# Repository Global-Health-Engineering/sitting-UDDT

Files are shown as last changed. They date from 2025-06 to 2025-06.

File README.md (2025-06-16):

<!-- badges: start -->


<!-- badges: end -->

<h1> Sitting Interface for Urine Diverting Dry Toilet </h1>

<b>Contributors</b>  
- Teymour D'Andrea <a href="https://orcid.org/0009-0000-6745-8110">
ORCID logo 0009-0000-6745-8110
</a> *author*  
- Jakub Tkaczuk <a href="https://orcid.org/0000-0001-7997-9423">
ORCID logo 0000-0001-7997-9423
</a> *supervisor, developer, maintainer*  
- Antoinette van der Merwe <a href="https://orcid.org/0000-0003-2489-8479">
ORCID logo 0000-0003-2489-8479
</a> *supervisor*  
- Elizabeth Tilley <a href="https://orcid.org/0000-0002-2095-9724">
ORCID logo 0000-0002-2095-9724
</a> *supervisor*  

<br>
<p align="middle"> 

<br><br>
This repository compliments the openly-accessible master’s thesis, available on the<br \>  
<a href="">ETH Research Collection</a>.
</p>

# Background

This repository compliments the Master's thesis of Teymour D'Andrea's, who adapted an existing open-source user interface of a Urine Diverting Dry Toilet (UDDT), designed by [EOOS](https://urinetrap.com/). The thesis proposes modifications to the design with an aim of making it more suitable for the South Africa’s context (i.e., sitting instead of squatting) and accessible to users of all age.

This repository contains mechanical drawings (both 3D and 2D) of modified steel molds, based on the original open-source concept to cast concrete user interfaces. These interfaces were tested for urine collection efficiency, yielding satisfactory results. Further optimization of the steel mold design is suggested to facilitate easier extraction.

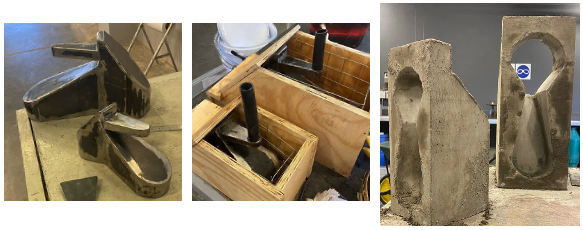
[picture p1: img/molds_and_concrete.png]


# Repository Structure

`cad` directory contains the CAD assemblies for the steel molds of the user interfaces (for adults and children) and the designs for the concrete seats. All files are provided in `.stl` and `.stp` formats.

`drawings` directory contains 2D drawings for all relevant parts of which the steel molds and the concrete seats are composed of.

# Design

## Steel mold

The origin for this work is the open-source UDDT design by [EOOS](https://urinetrap.com/).

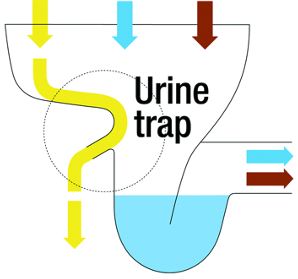
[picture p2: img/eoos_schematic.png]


One sitting UDDT design is proposed for adult users:

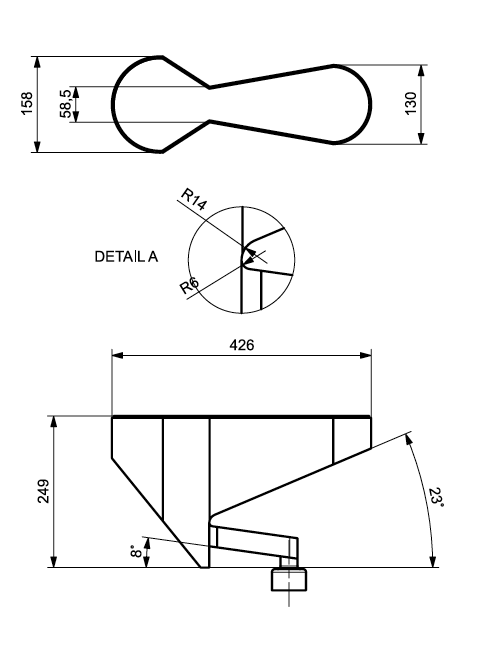
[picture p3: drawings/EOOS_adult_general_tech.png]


and one for children users:

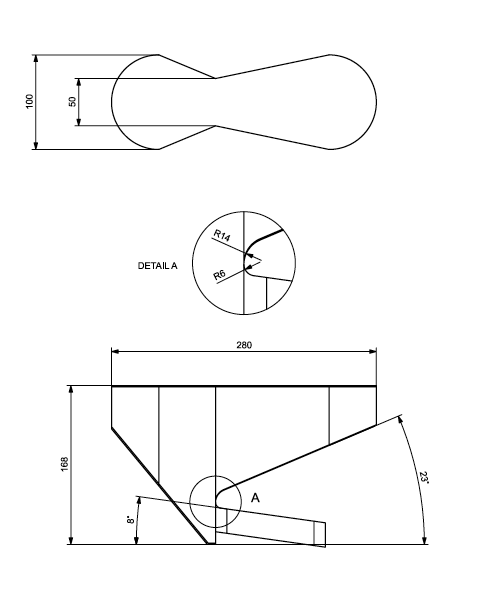
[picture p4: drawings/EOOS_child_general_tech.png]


Each of these drawings is supplemented by six additional technical drawings, detailing the geometry of parts used in the steel mold construction:

- `drawings/EOOS_adult_tech_1.pdf` and `drawings/EOOS_child_tech_1.pdf`
- `drawings/EOOS_adult_tech_2.pdf` and `drawings/EOOS_child_tech_2.pdf`
- `drawings/EOOS_adult_tech_3.pdf` and `drawings/EOOS_child_tech_3.pdf`
- `drawings/EOOS_adult_tech_4.pdf` and `drawings/EOOS_child_tech_4.pdf`
- `drawings/EOOS_adult_tech_5.pdf` and `drawings/EOOS_child_tech_5.pdf`
- `drawings/EOOS_adult_tech_6.pdf` and `drawings/EOOS_child_tech_6.pdf`

Names of these drawings refer to the numbers shown on the exploded view of a complete steel mold, allowing for easy part identification:

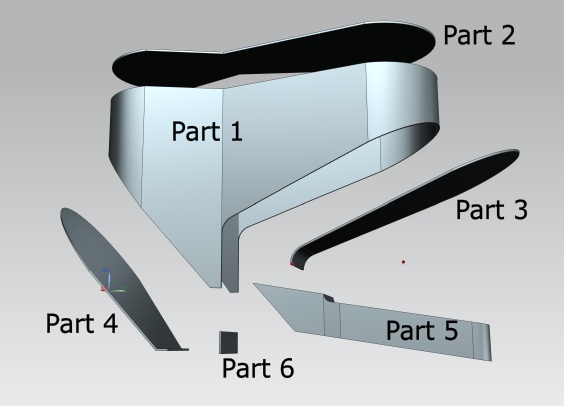
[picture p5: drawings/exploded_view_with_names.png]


## Seat

The UDDT part fits into a concrete seat, which was also designed and built:

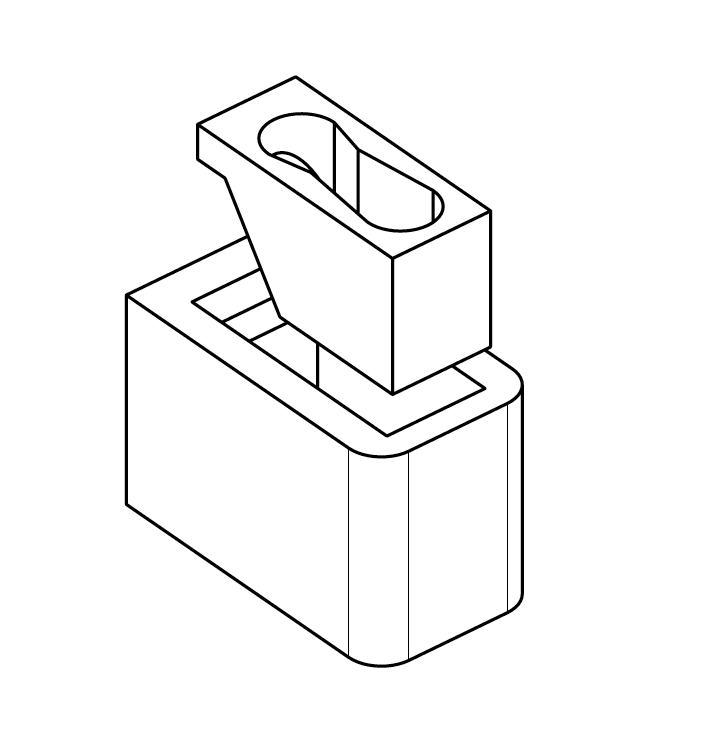
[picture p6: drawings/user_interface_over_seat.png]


The dimensions for both adult and children versions are available in `drawings/tech_seat_adult.pdf` and `drawings/tech_seat_child.pdf`.

## Draft Angle for Demolding

A draft angle of 3 degrees on all walls is suggested to facilitate concrete demolding process.

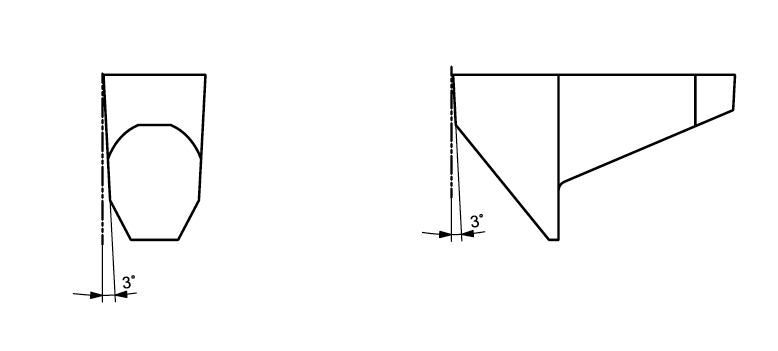
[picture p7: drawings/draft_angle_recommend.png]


## Urine Diversion Performance

The performance of sitting UDDT interfaces for urine diversion was evaluated with the urinator (open-source tool for this purpose, proposed by [EOOS](https://urinetrap.com/)). The results are presented below:

| | Male Urethra | | Female Urethra | |
|---|---|---|---|---|
| | Avg. efficiency [%] | Std. Dev.| Avg. efficiency [%] | Std. Dev.|
| Adult 1 | 83.5 | 6.0 | 81.0 | 6.5 |
| Adult 2 | 81.8 | 4.7 | 81.3 | 7.8 |
| Children 1 | 88.7 | 4.0 | 85.0 | 5.6 |
| Children 2 | 88.7 | 4.3 | 84.7 | 4.0 |

The results above show that the interface was able to prevent between 81% and 88% of liquid from entering the feces compartment of the UDDT toilet, calculated as a diverted volume of liquid per total volume of liquid, which passed through the urinator.

## Toilet Block Construction

Above designs were constructed and integrated into new toilet blocks for Konanani Crèche at the outskirts of Pretoria, South Africa.

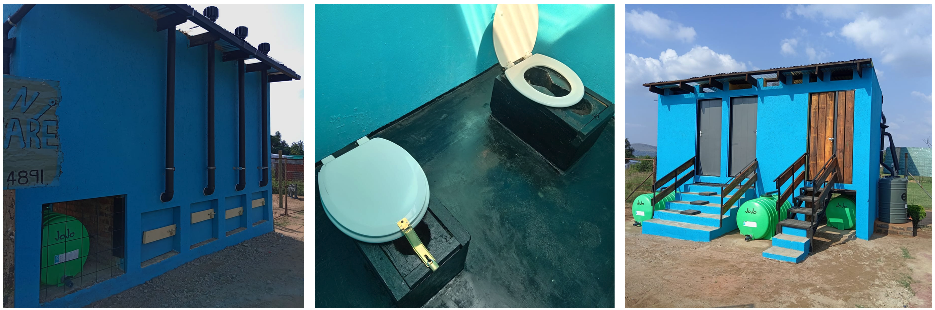
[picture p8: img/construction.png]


# License

The complete design is licensed under [Creative Commons Attribution 4.0 International](https://github.com/Global-Health-Engineering/sitting-UDDT/blob/main/LICENSE.md).

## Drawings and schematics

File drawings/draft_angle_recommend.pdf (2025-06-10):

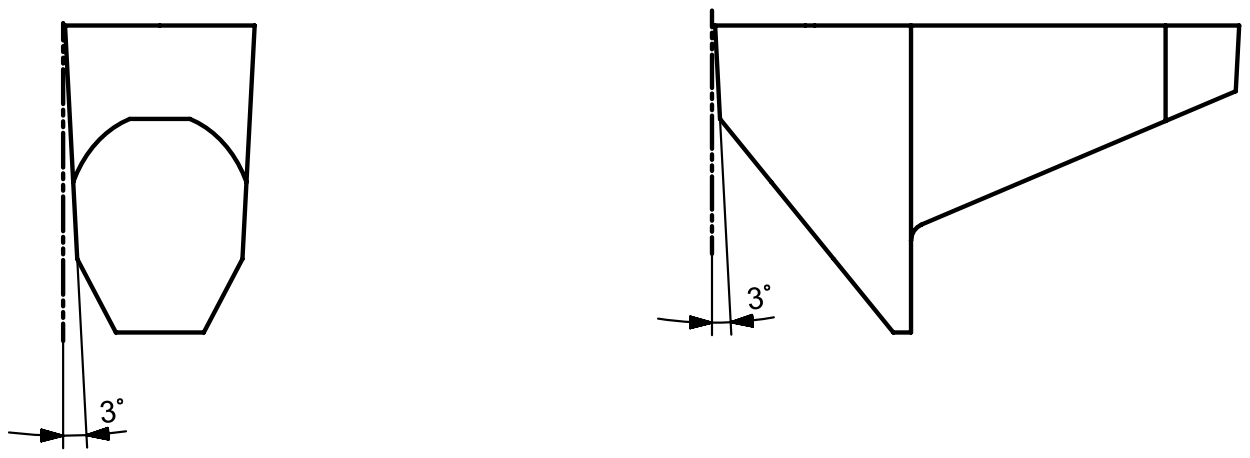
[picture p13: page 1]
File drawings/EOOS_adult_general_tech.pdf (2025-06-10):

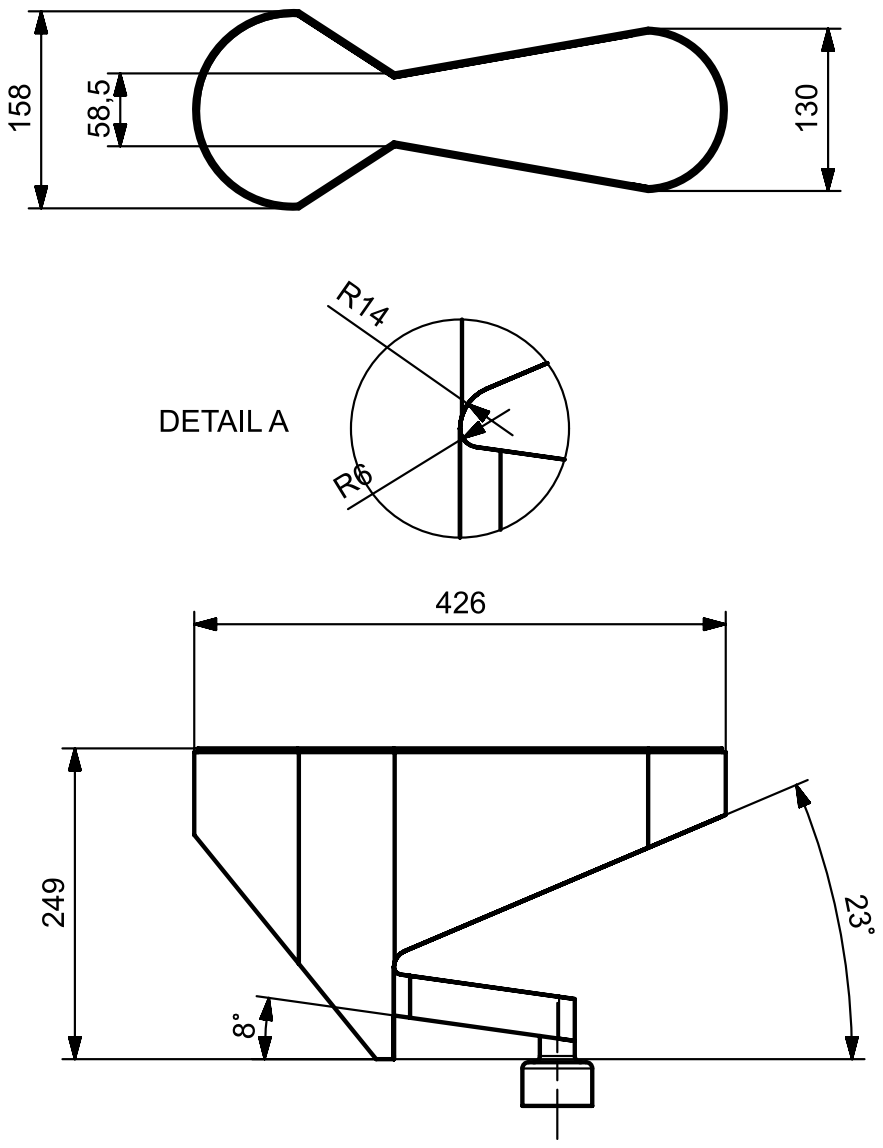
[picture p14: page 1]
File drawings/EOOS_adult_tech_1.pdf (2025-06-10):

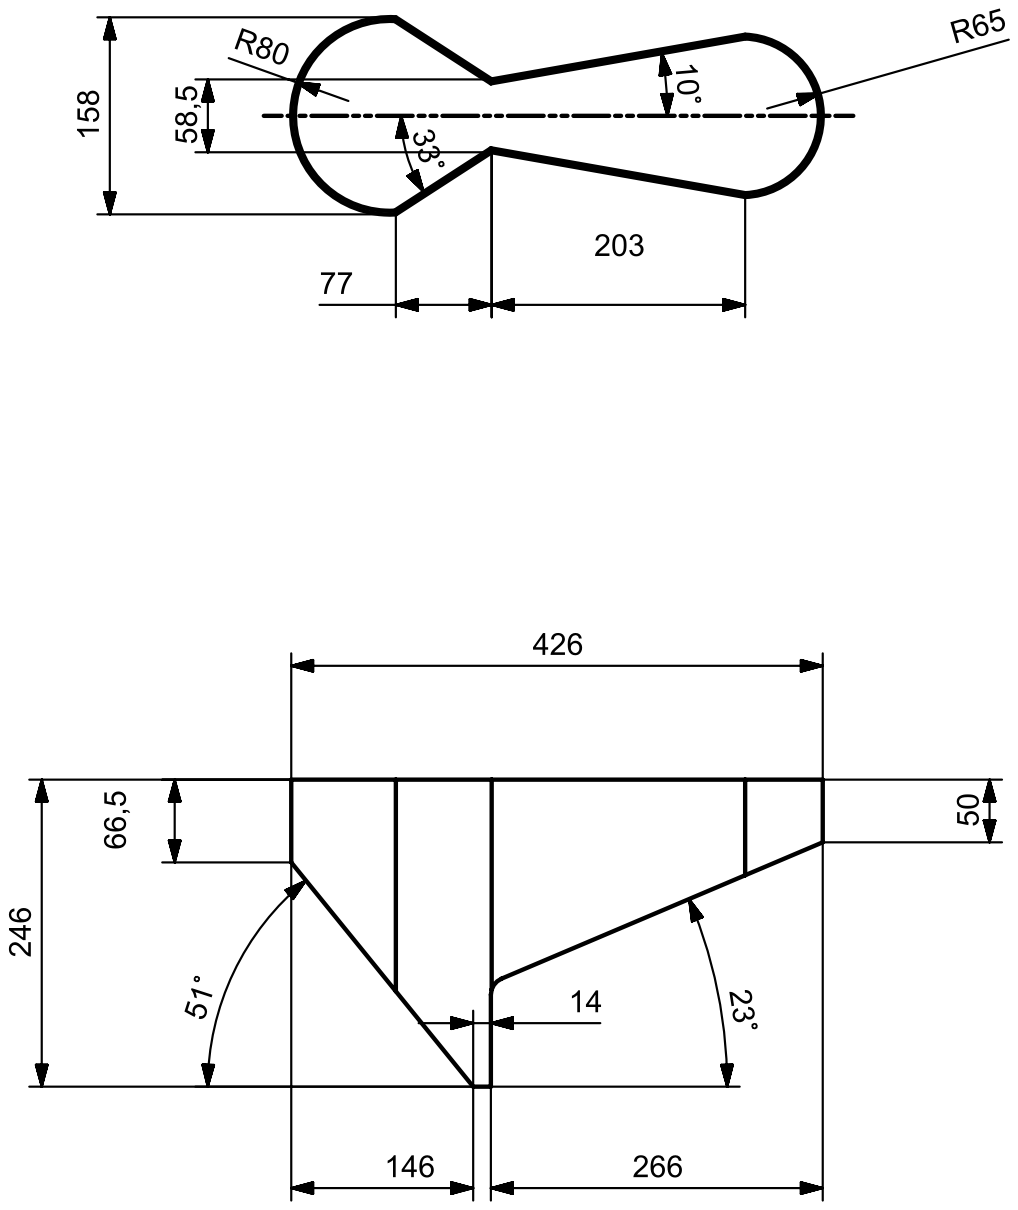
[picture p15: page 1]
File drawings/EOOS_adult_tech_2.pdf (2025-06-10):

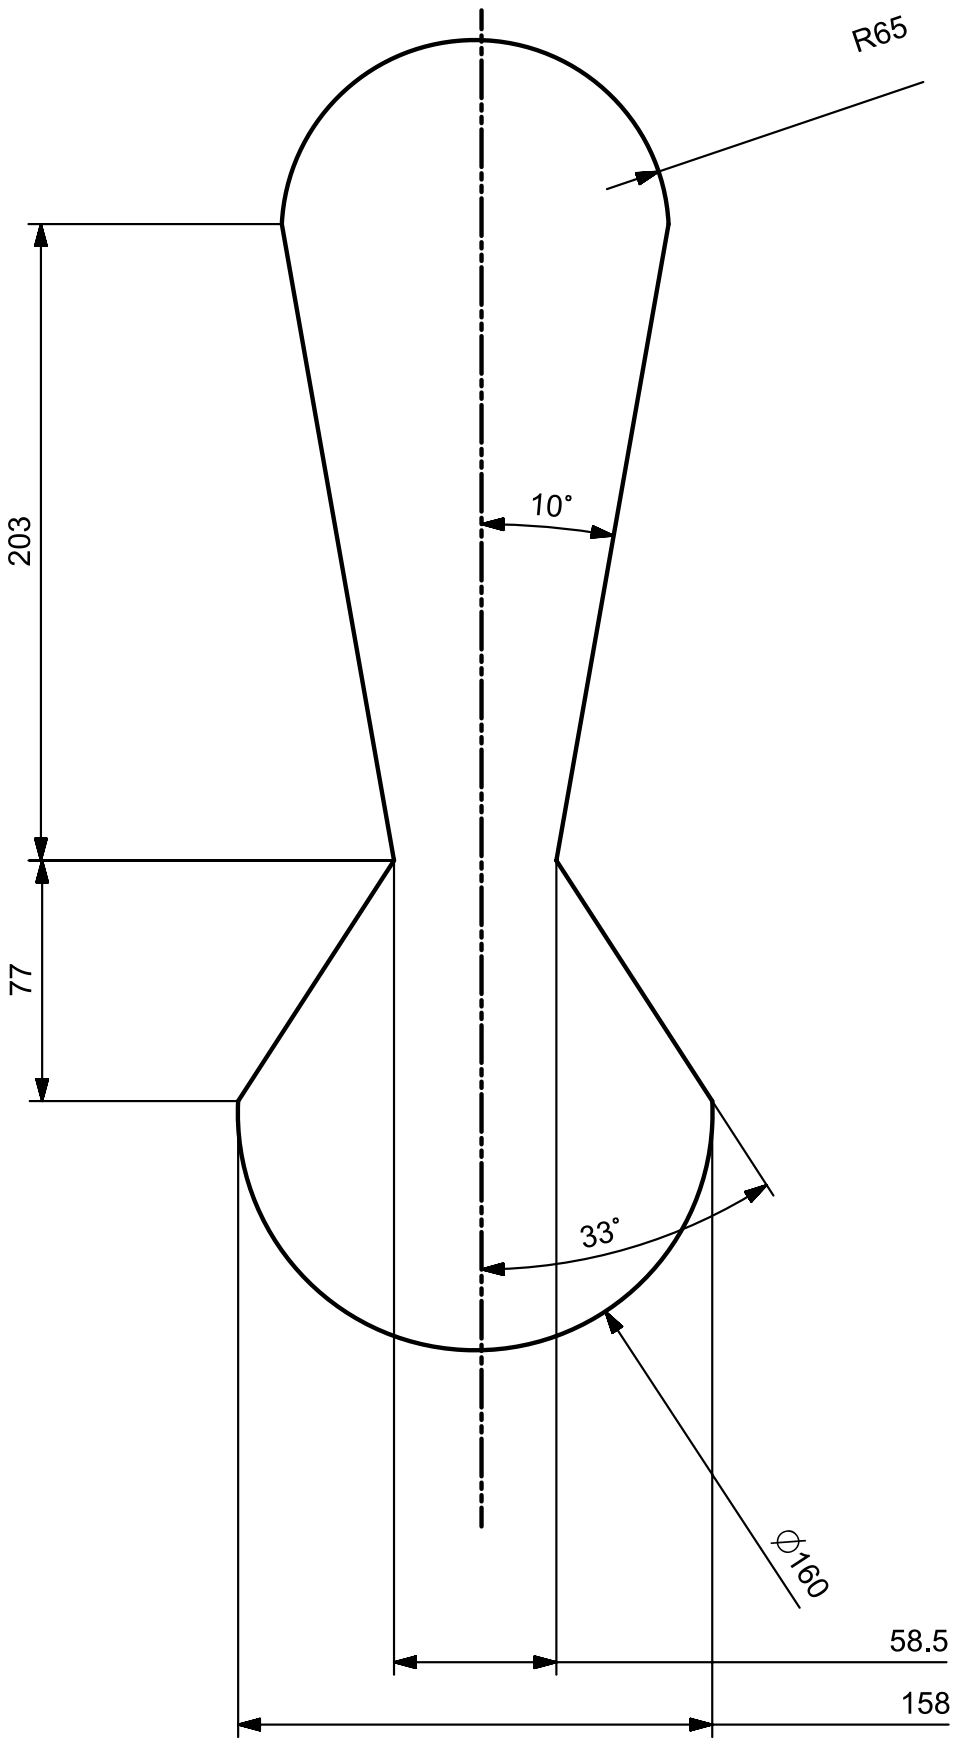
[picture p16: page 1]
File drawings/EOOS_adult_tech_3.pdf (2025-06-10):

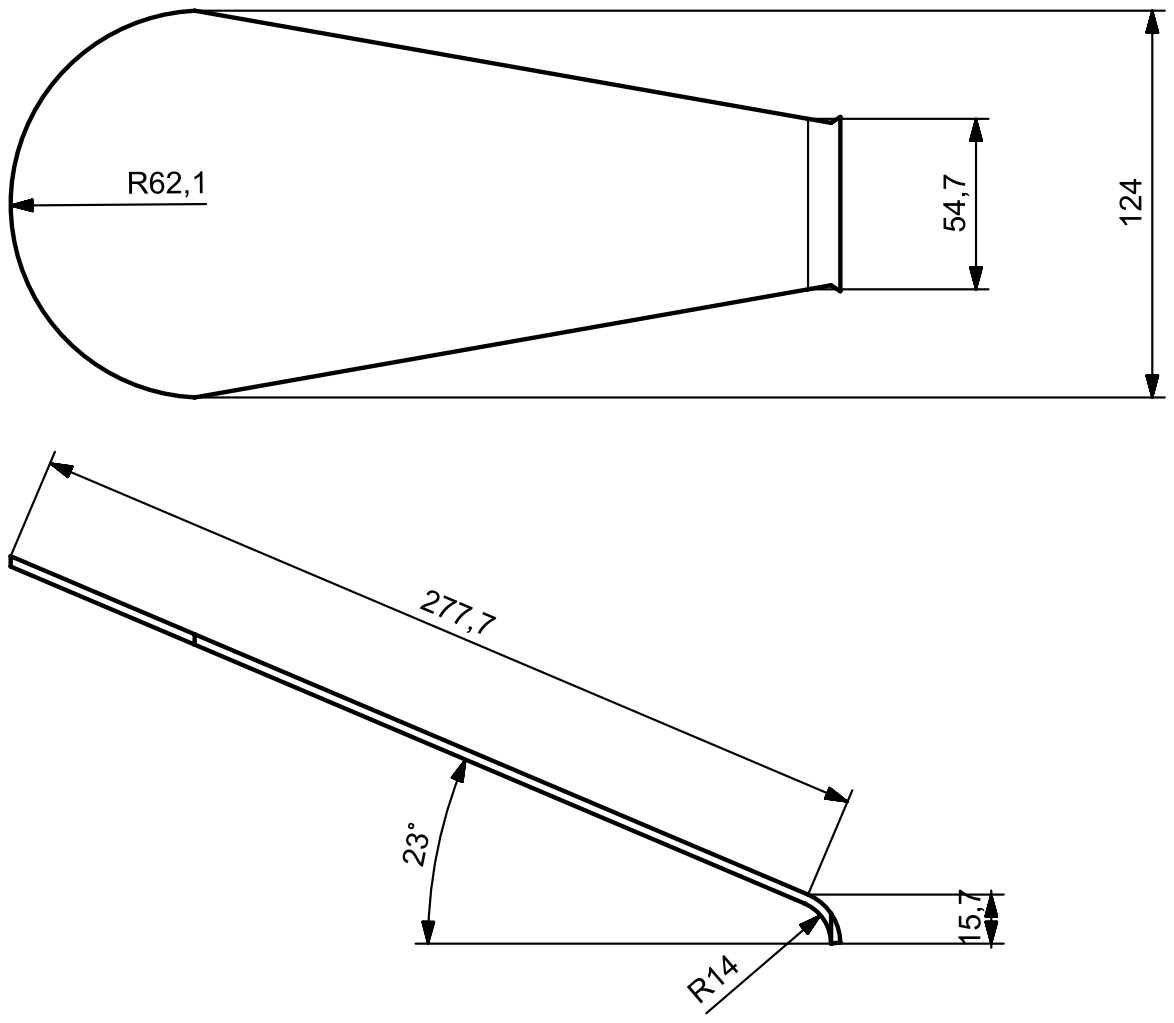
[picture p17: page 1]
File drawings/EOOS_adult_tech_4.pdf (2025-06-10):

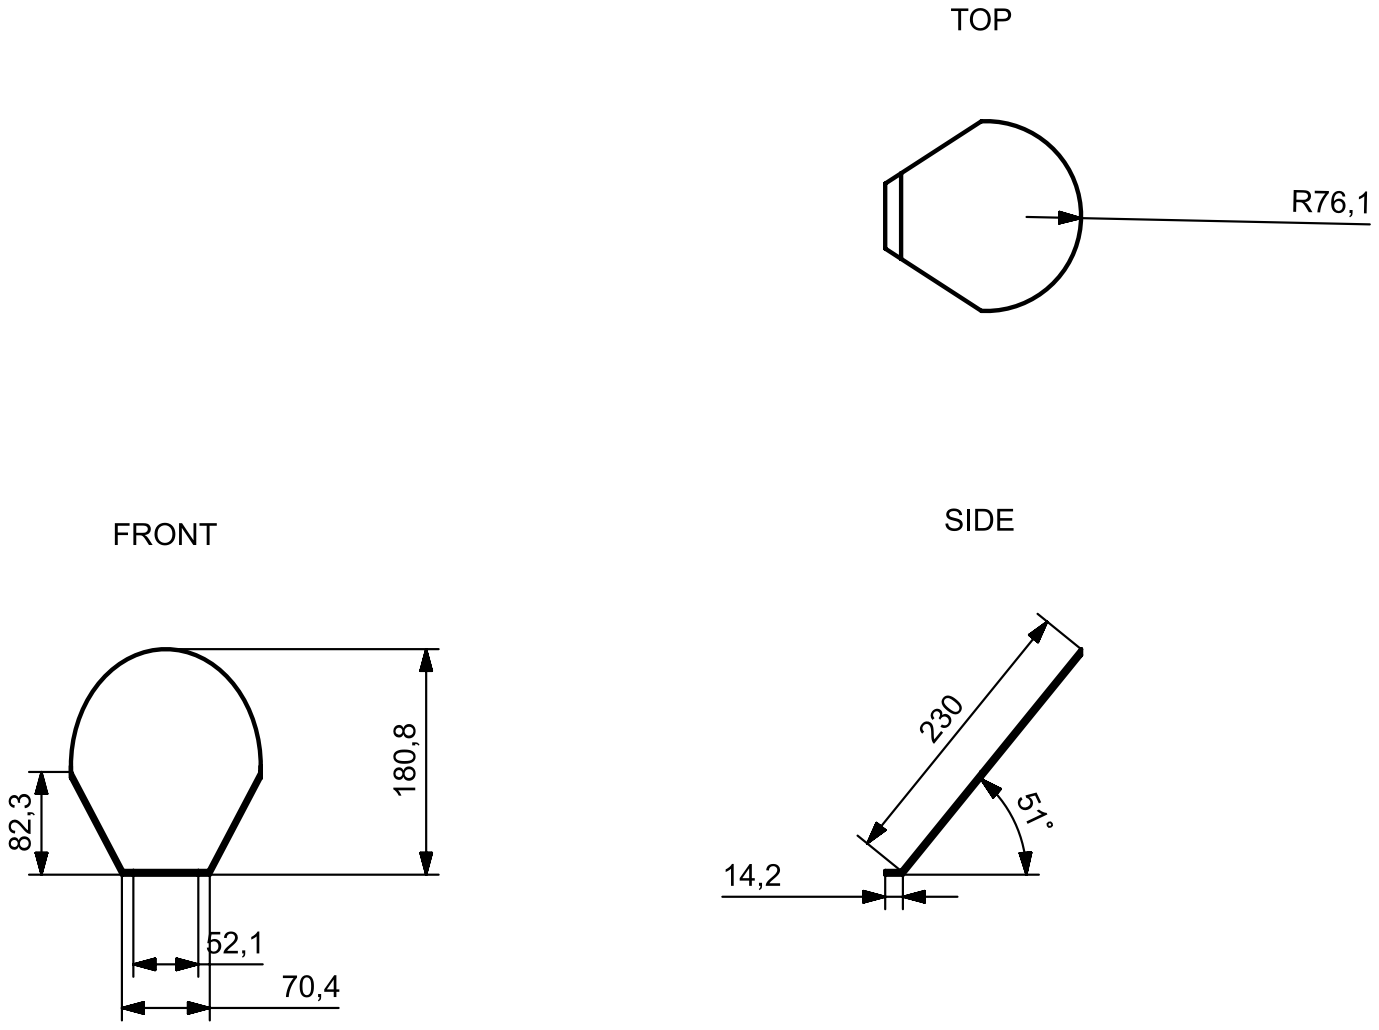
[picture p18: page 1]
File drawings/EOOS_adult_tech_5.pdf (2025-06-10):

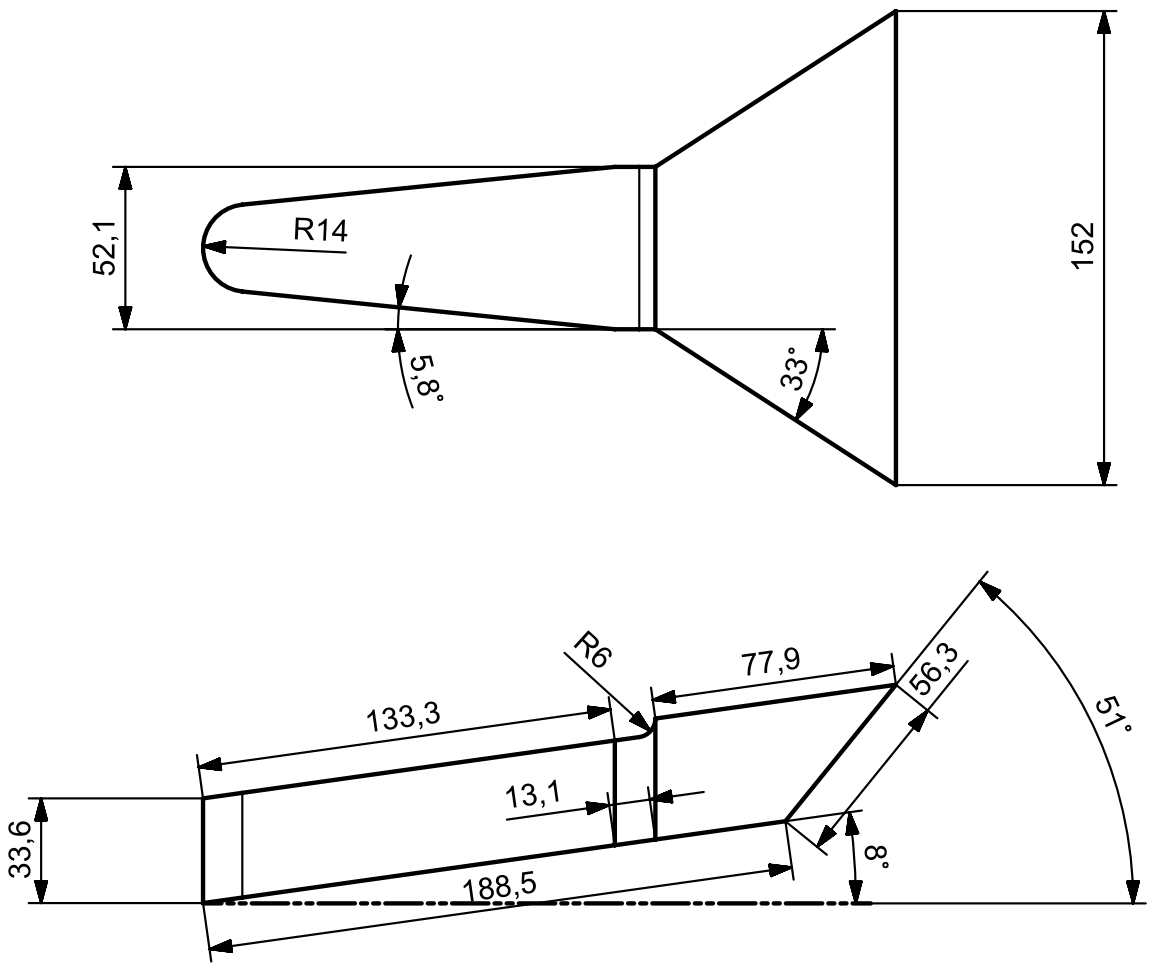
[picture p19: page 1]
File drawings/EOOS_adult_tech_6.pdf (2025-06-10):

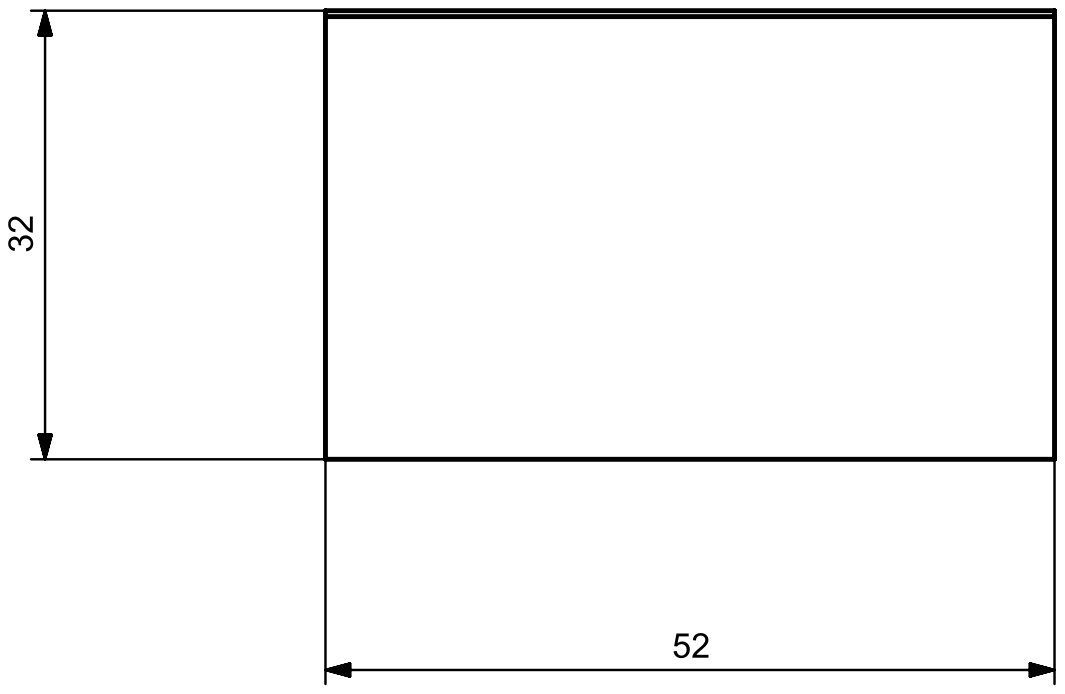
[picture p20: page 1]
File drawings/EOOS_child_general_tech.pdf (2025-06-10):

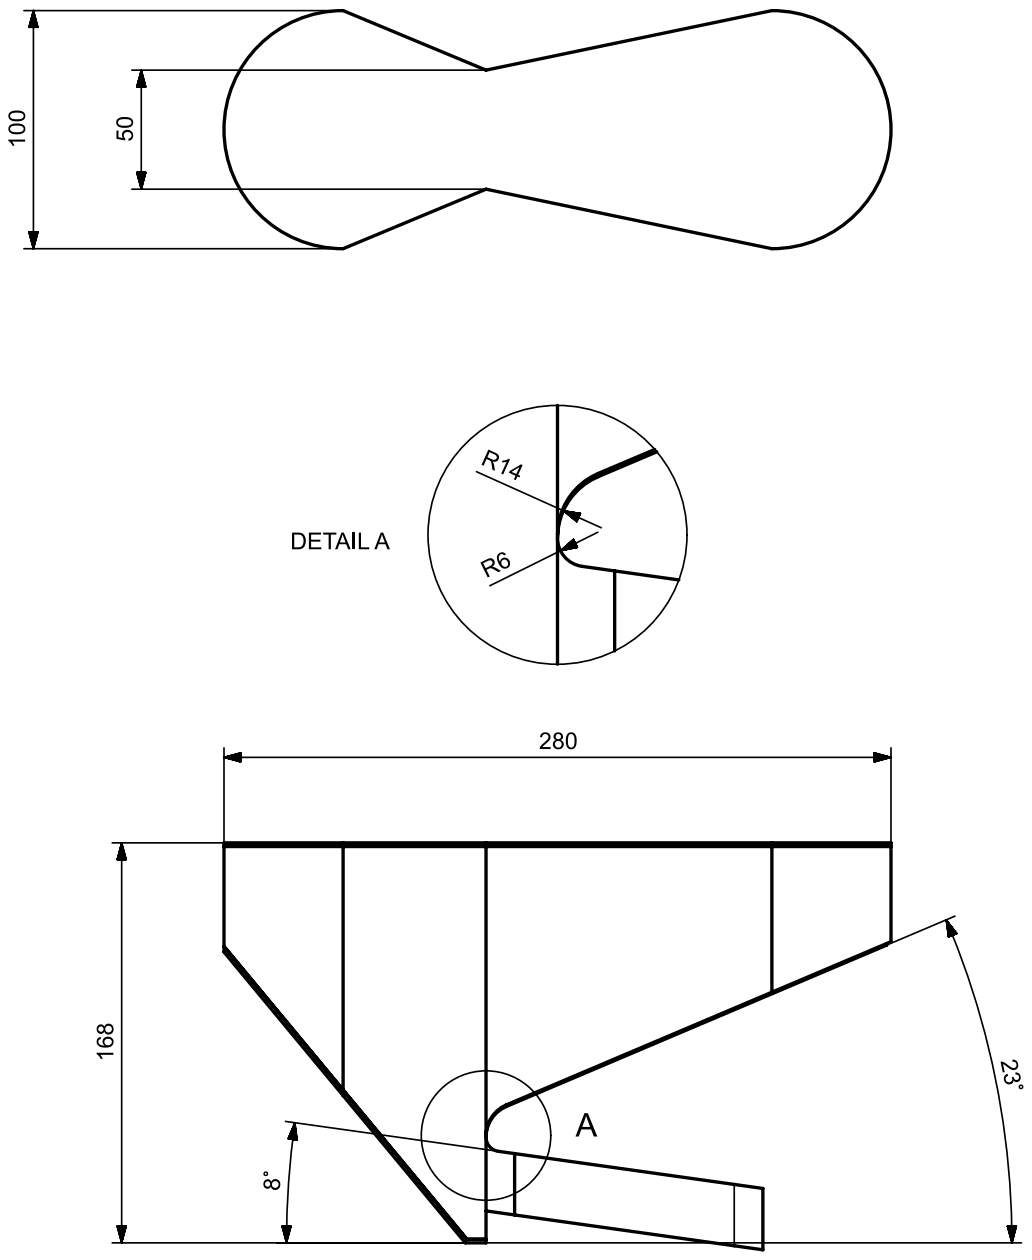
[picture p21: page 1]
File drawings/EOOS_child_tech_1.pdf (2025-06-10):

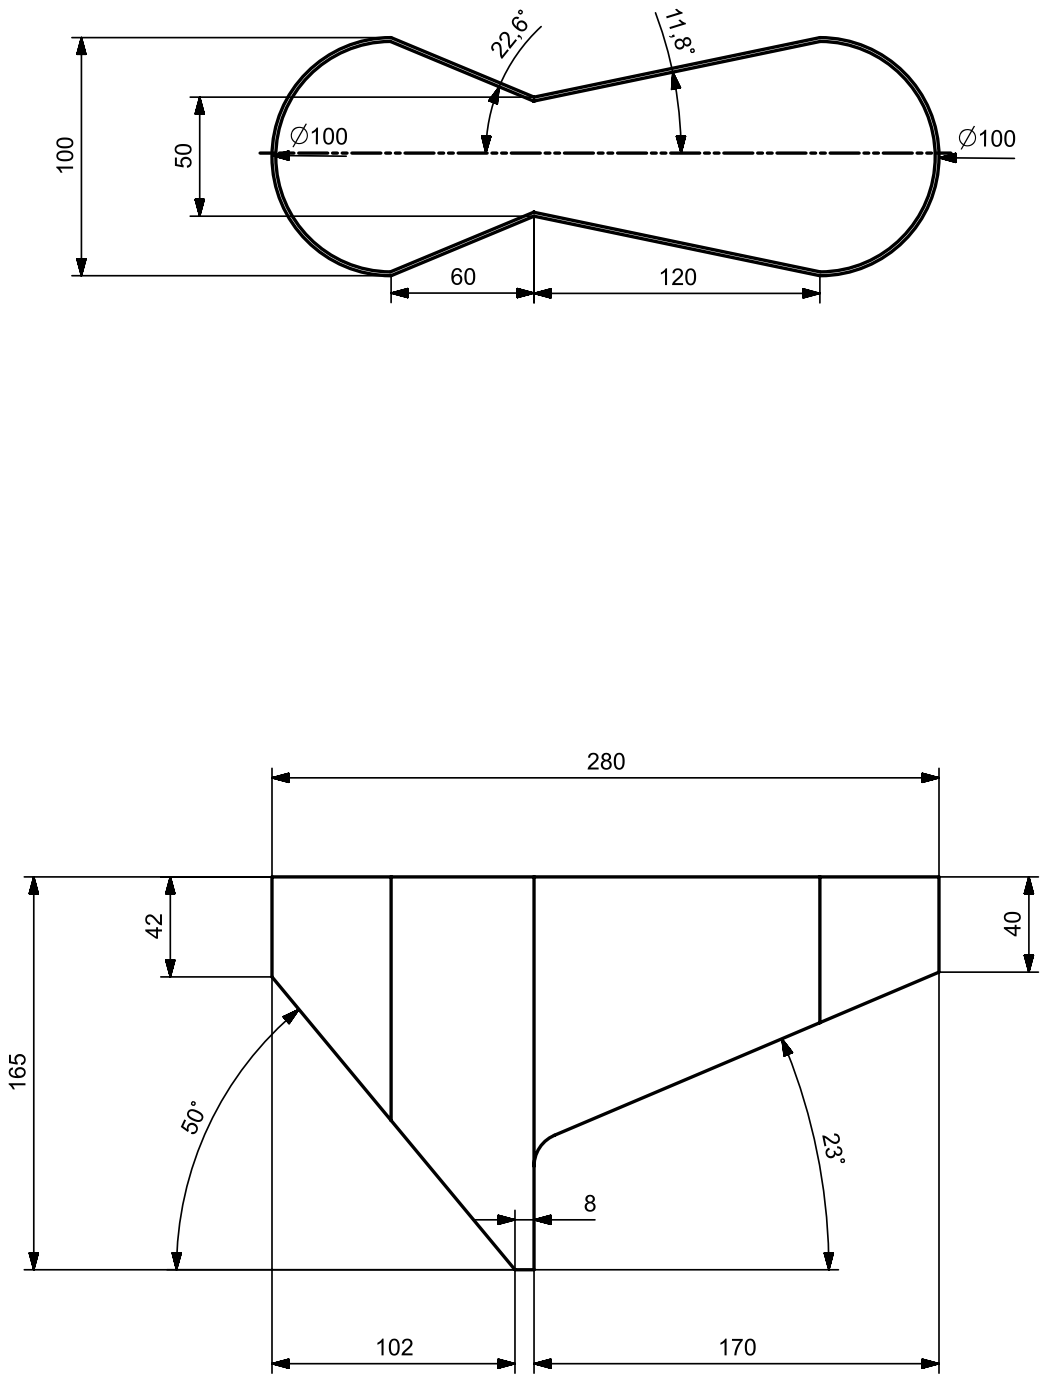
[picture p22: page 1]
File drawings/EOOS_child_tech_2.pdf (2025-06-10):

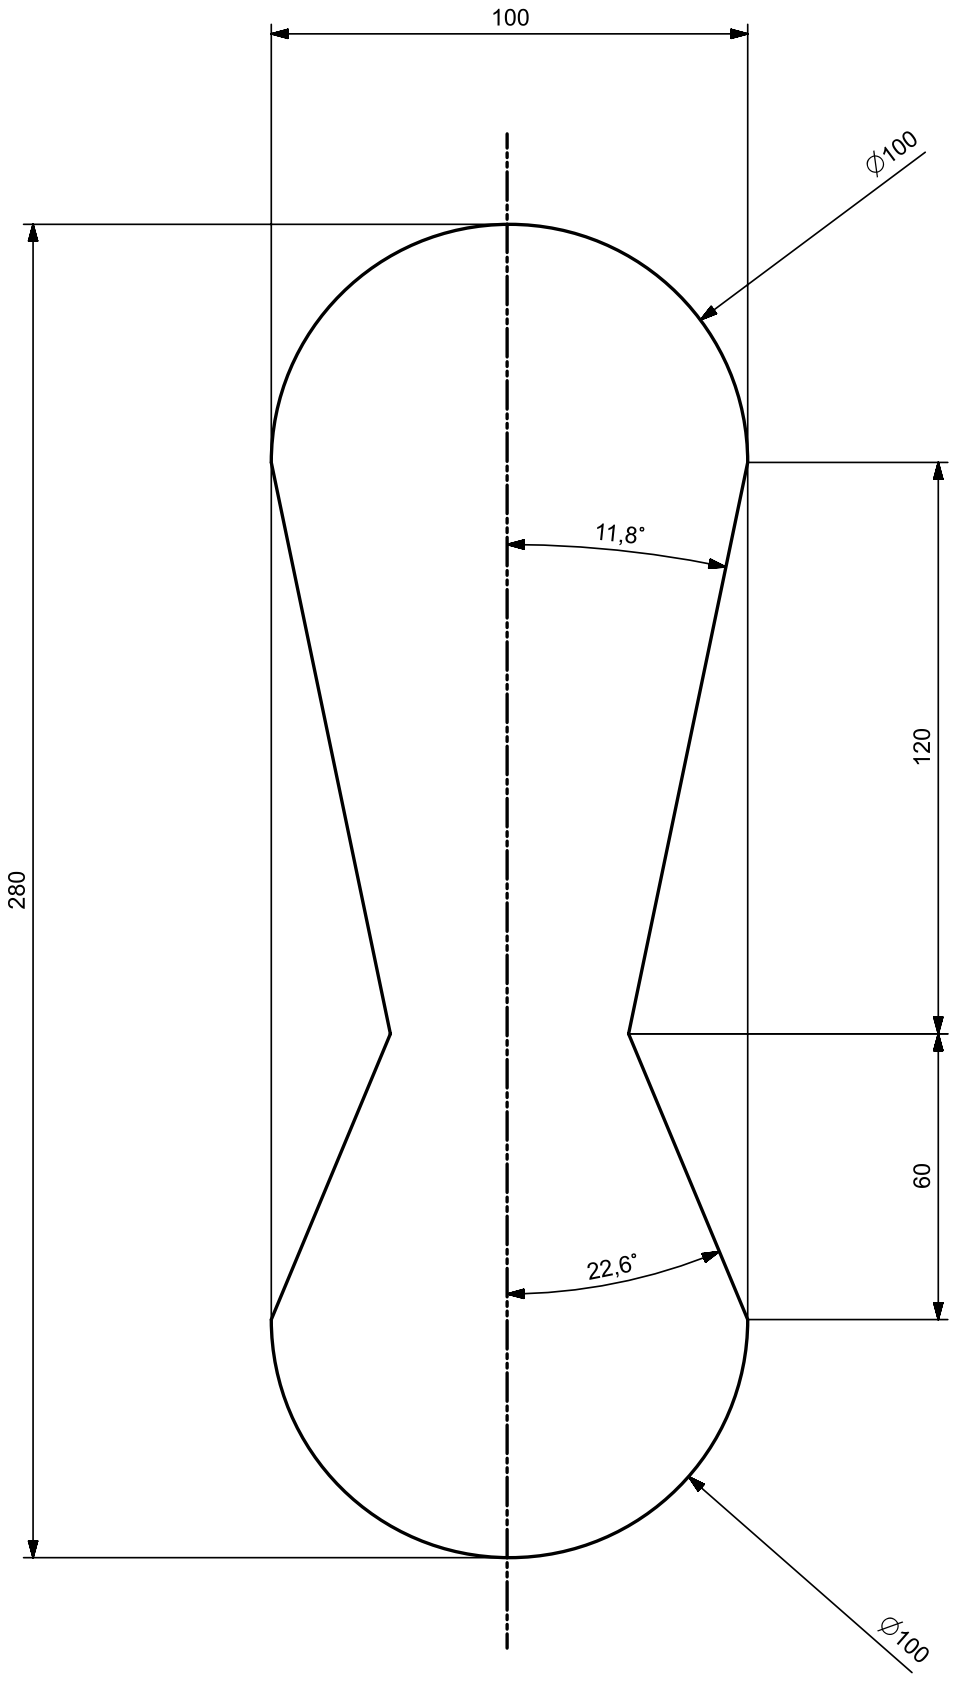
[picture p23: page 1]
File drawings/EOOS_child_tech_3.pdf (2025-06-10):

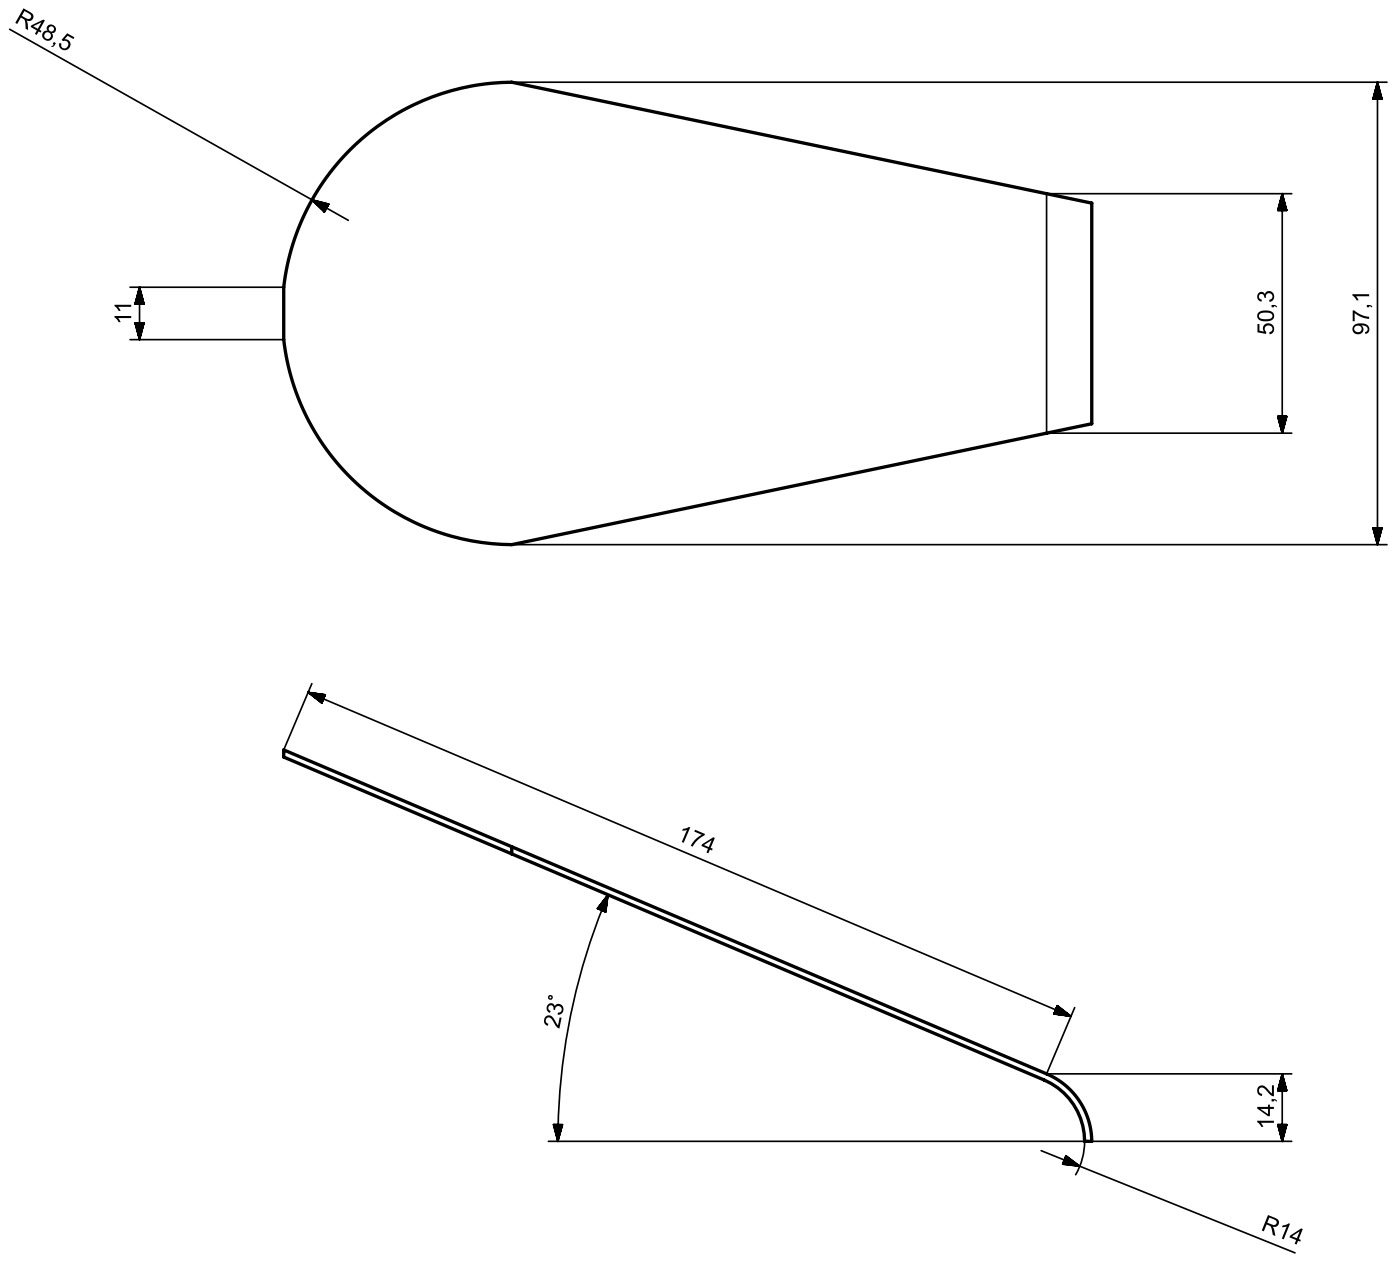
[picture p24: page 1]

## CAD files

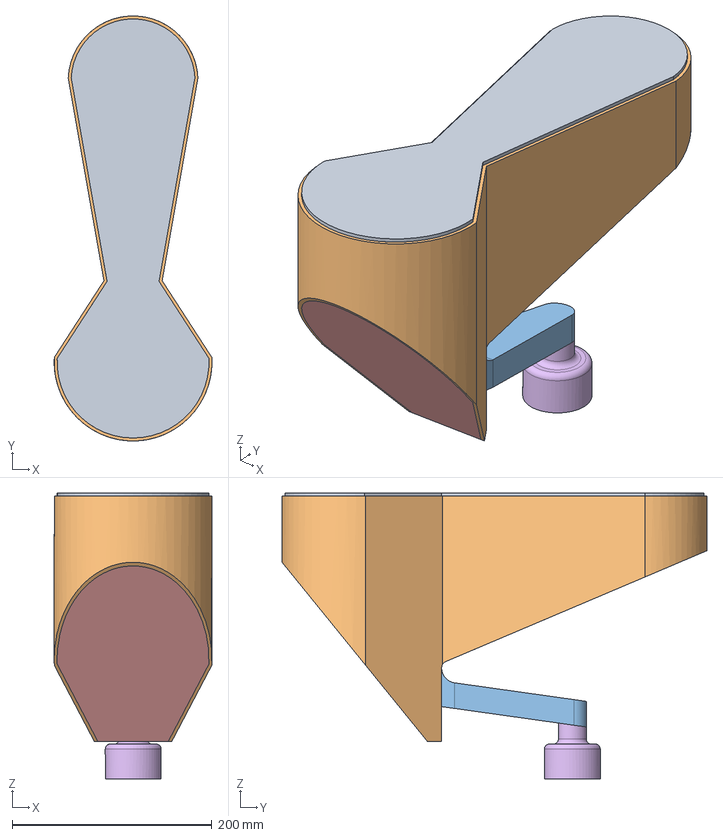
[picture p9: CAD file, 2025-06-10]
cad/EOOS_UI_adults.stp
158.0 x 425.9 x 286.5 mm
EOOSmod9
EOOSmod_3
EOOSmod2impr
EOOSmod5
EOOSmod_6
EOOSmod7
EOOSmod8

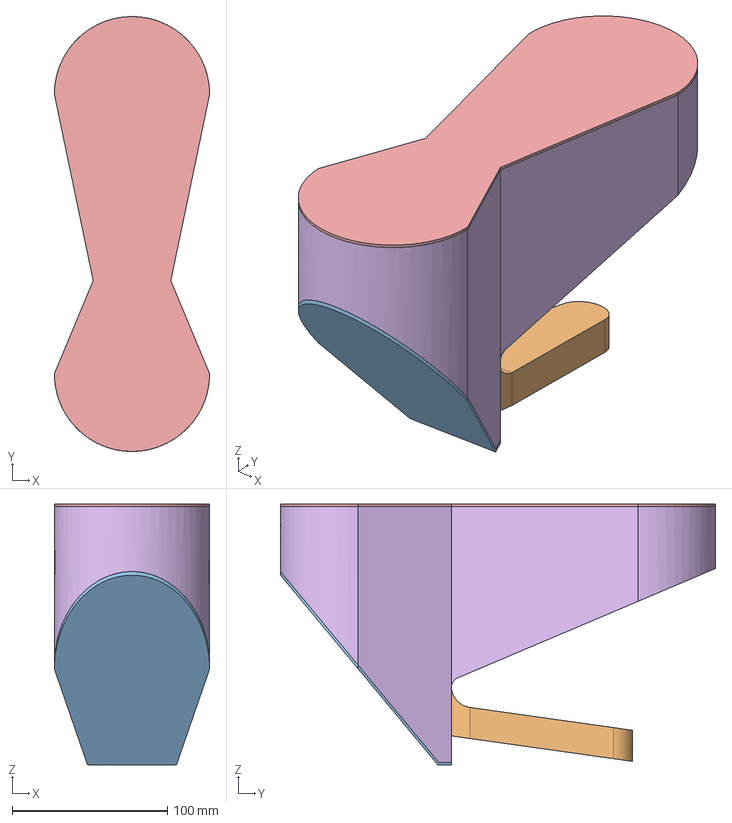
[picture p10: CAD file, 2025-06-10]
cad/EOOS_UI_children.stp
100.0 x 280.0 x 168.0 mm
EOOSchildre_7
EOOSchildren_5
EOOSchildren_4
EOOSchildren_3
EOOSchildren_2
EOOSchildren_1

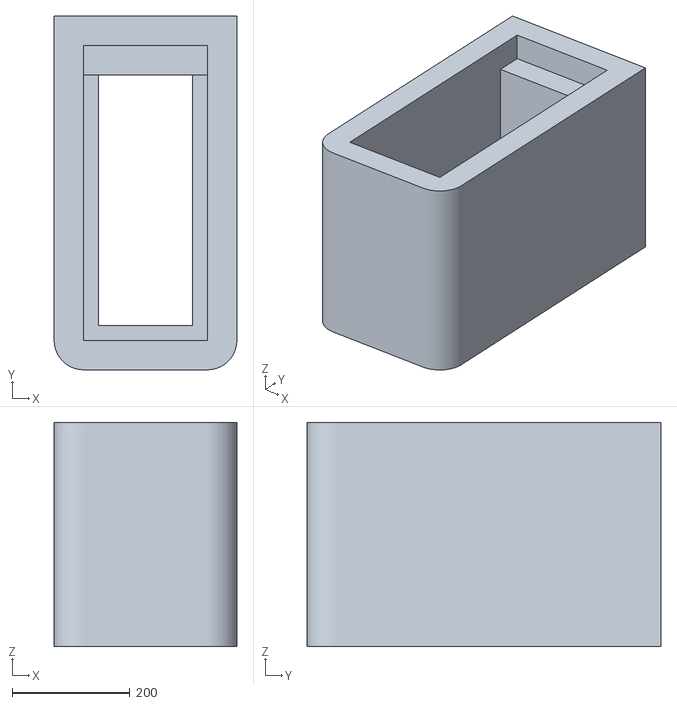
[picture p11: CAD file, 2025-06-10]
cad/seat_adult.stl
310.0 x 600.0 x 380.0

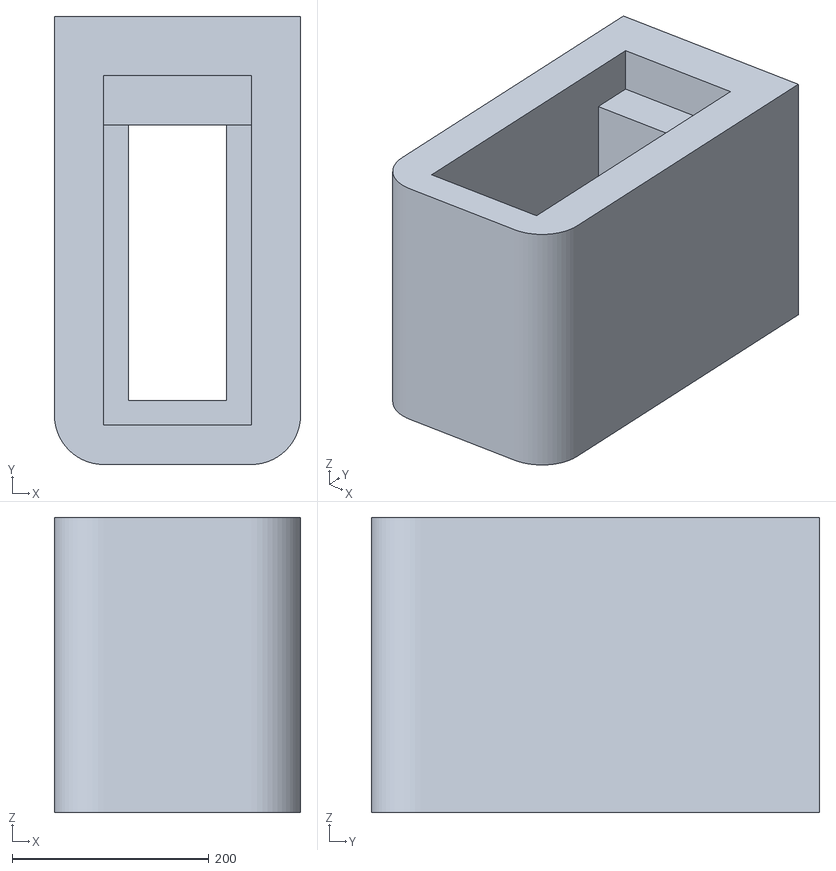
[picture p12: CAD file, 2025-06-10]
cad/seat_child.stl
250.0 x 455.0 x 300.0

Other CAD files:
cad/EOOS_UI_adults.stl
cad/EOOS_UI_children.stl

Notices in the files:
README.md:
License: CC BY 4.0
